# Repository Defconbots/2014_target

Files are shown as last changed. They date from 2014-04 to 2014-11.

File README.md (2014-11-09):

# Defconbots 2014 Target Hardware/Firmware

## Overview

This is the hardware and firmware design files for the defconbots 2014 laser target. It uses an [MSP430G2452](http://www.ti.com/product/msp430g2452) microcontroller and [TCS3414CS](http://www.ams.com/eng/Products/Light-Sensors/Color-Sensor/TCS3414) light detector to detect laser hits.

The board is designed in EagleCad 6.x. All part numbers are mouser numbers for easy BOM export.

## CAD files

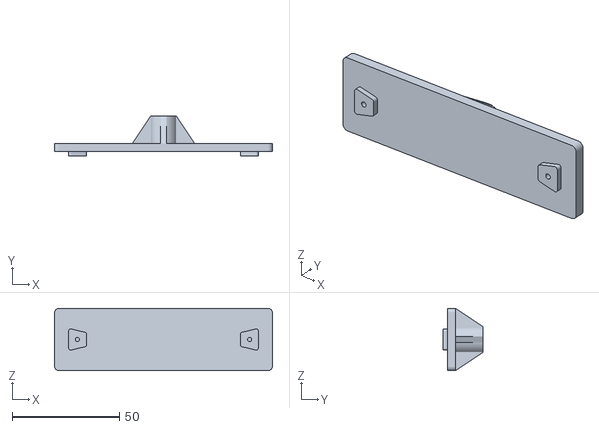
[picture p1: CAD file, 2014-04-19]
mech/train_mount.STL
101.6 x 18.5 x 29.0

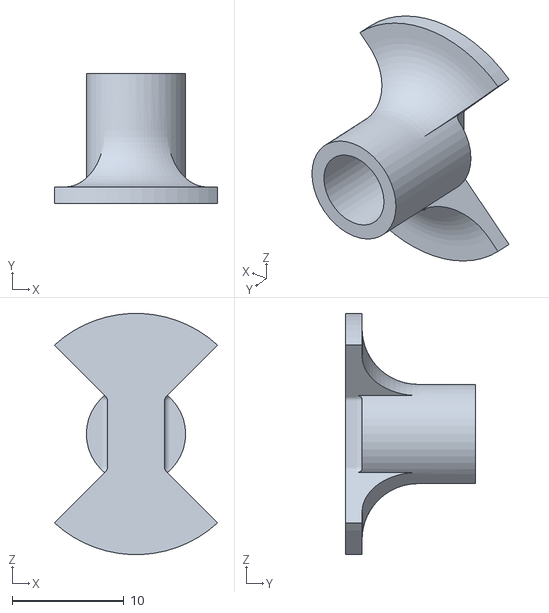
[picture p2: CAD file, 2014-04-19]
mech/pcb_mount.STL
14.6 x 11.7 x 21.6

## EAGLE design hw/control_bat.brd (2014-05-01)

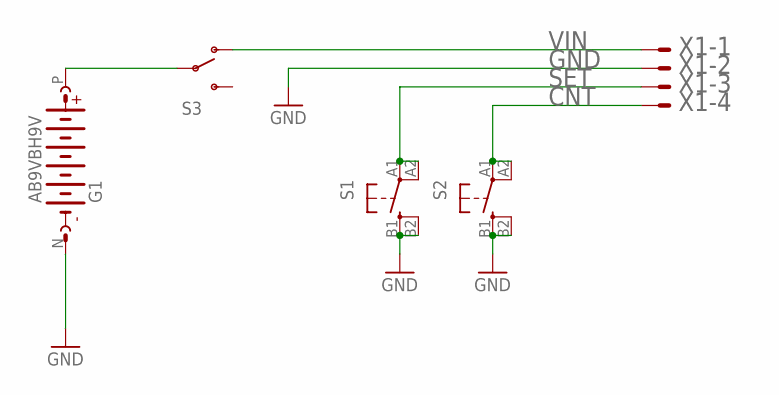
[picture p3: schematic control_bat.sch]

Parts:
G1: AB9VBH9V; BH9V-PC-ND
S1, S2: TAC_SWITCHD6F; D6F
S3: SWITCH-SPST; EG1270
X1: DF13-4P-1.25V(50); 53398-04

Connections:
CNT: S2.A1 (1), S2.A2 (2), X1.4
GND: G1.N (-), S1.B1 (3), S1.B2 (4), S2.B1 (3), S2.B2 (4), X1.2
unnamed: G1.P (+), S3.P$2
SET: S1.A1 (1), S1.A2 (2), X1.3
VIN: S3.P$1 (O), X1.1

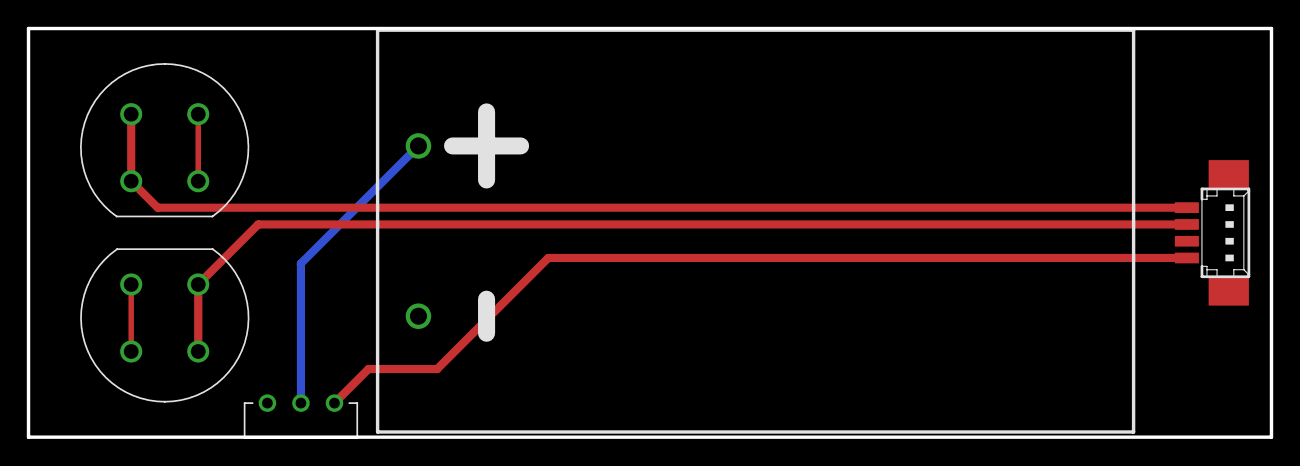
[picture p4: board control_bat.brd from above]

Board: 2 copper layers, 92.7 x 30.5 mm, 5 parts (0 on the bottom side), 5 nets.

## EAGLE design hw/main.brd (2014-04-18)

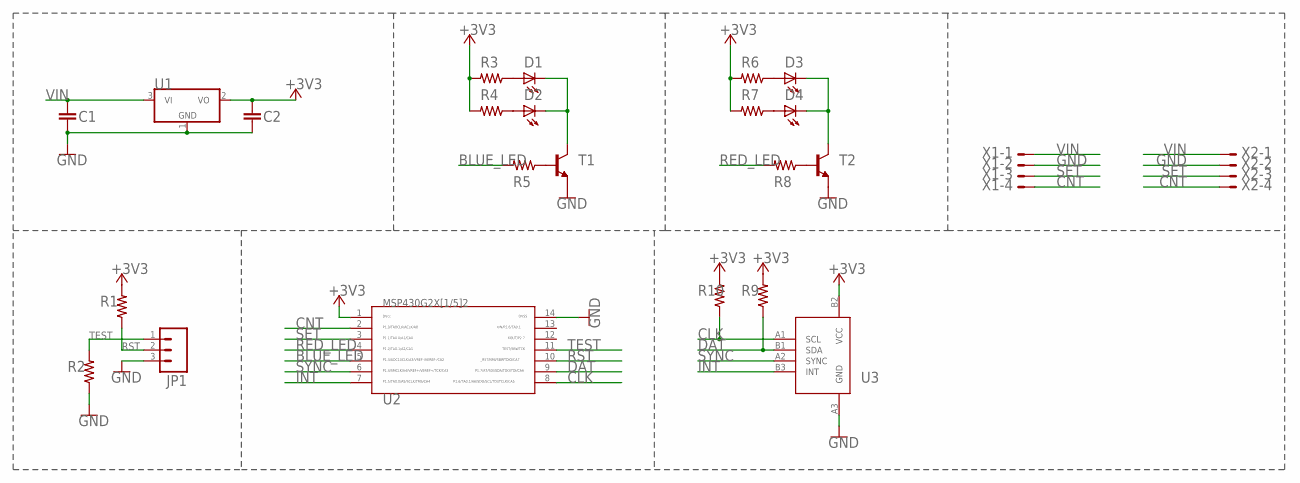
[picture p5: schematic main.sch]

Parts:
C1, C2: C1608X5R1C106M080AB; 0603-CAP
D1, D2: VLMB1300-GS08; LED-0603
D3, D4: VLMS1300-GS08; LED-0603
JP1: M03PTH; 1X03
R1, R2: RK73H1JTTD4702F; R0603
R3, R4, R5, R6, R7, R8: CRCW0603200RFKEA; R0603
R9, R10: RK73H1JTTD4701F; R0603
T1, T2: PMBT4401,215; SOT23-BEC
U1: MCP1703T-3002E/CB; SOT23
U2: MSP430G2452IPW14R; PW14
U3: TCS3414CS; CS-6
X1, X2: DF13-4P-1.25V(50); 53398-04

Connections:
+3V3: C2.1, R1.2, R3.2, R4.2, R6.2, R7.2, R9.2, R10.2, U1.2 (VO), U2.1, U3.B2 (VCC)
BLUE_LED: R5.2, U2.5
CLK: R10.1, U2.8, U3.A1 (SCL)
CNT: U2.2, X1.4, X2.4
DAT: R9.1, U2.9, U3.B1 (SDA)
GND: C1.2, C2.2, JP1.3, R2.1, T1.E, T2.E, U1.1 (GND), U2.14, U3.A3 (GND), X1.2, X2.2
INT: U2.7, U3.B3 (INT)
LED: D1.C, D2.C, T1.C
unnamed: D4.A, R7.1
unnamed: D3.C, D4.C, T2.C
unnamed: R8.1, T2.B
unnamed: D2.A, R4.1
unnamed: D1.A, R3.1
unnamed: D3.A, R6.1
unnamed: R5.1, T1.B
RED_LED: R8.2, U2.4
RST: JP1.2, R1.1, U2.10
SET: U2.3, X1.3, X2.3
SYNC: U2.6, U3.A2 (SYNC)
TEST: JP1.1, R2.2, U2.11
VIN: C1.1, U1.3 (VI), X1.1, X2.1

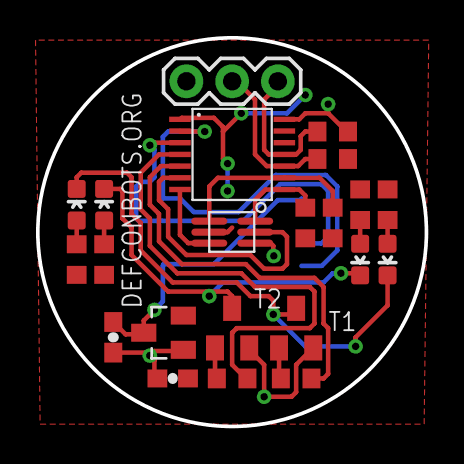
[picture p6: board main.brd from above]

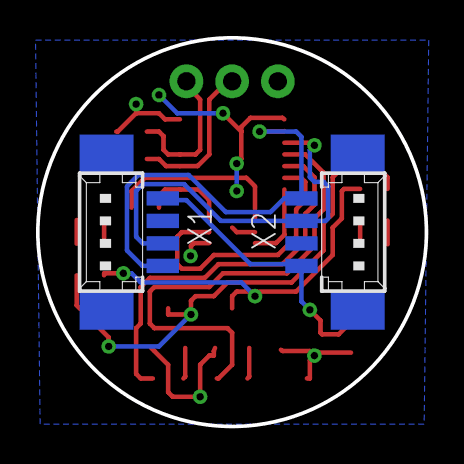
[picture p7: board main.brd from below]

Board: 2 copper layers, 21.6 x 21.6 mm, 24 parts (2 on the bottom side), 21 nets.

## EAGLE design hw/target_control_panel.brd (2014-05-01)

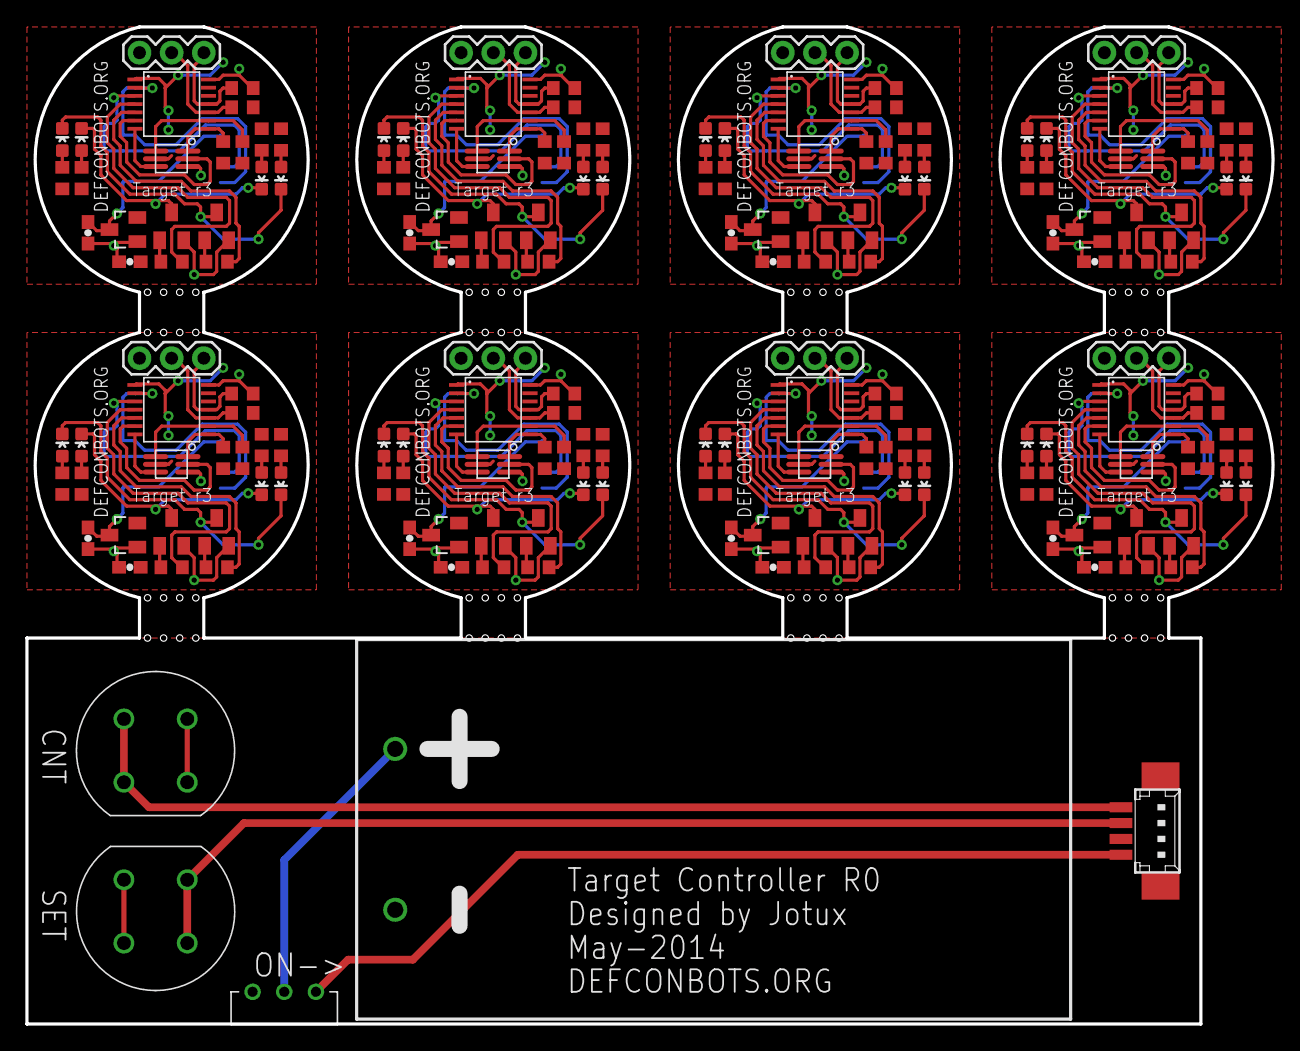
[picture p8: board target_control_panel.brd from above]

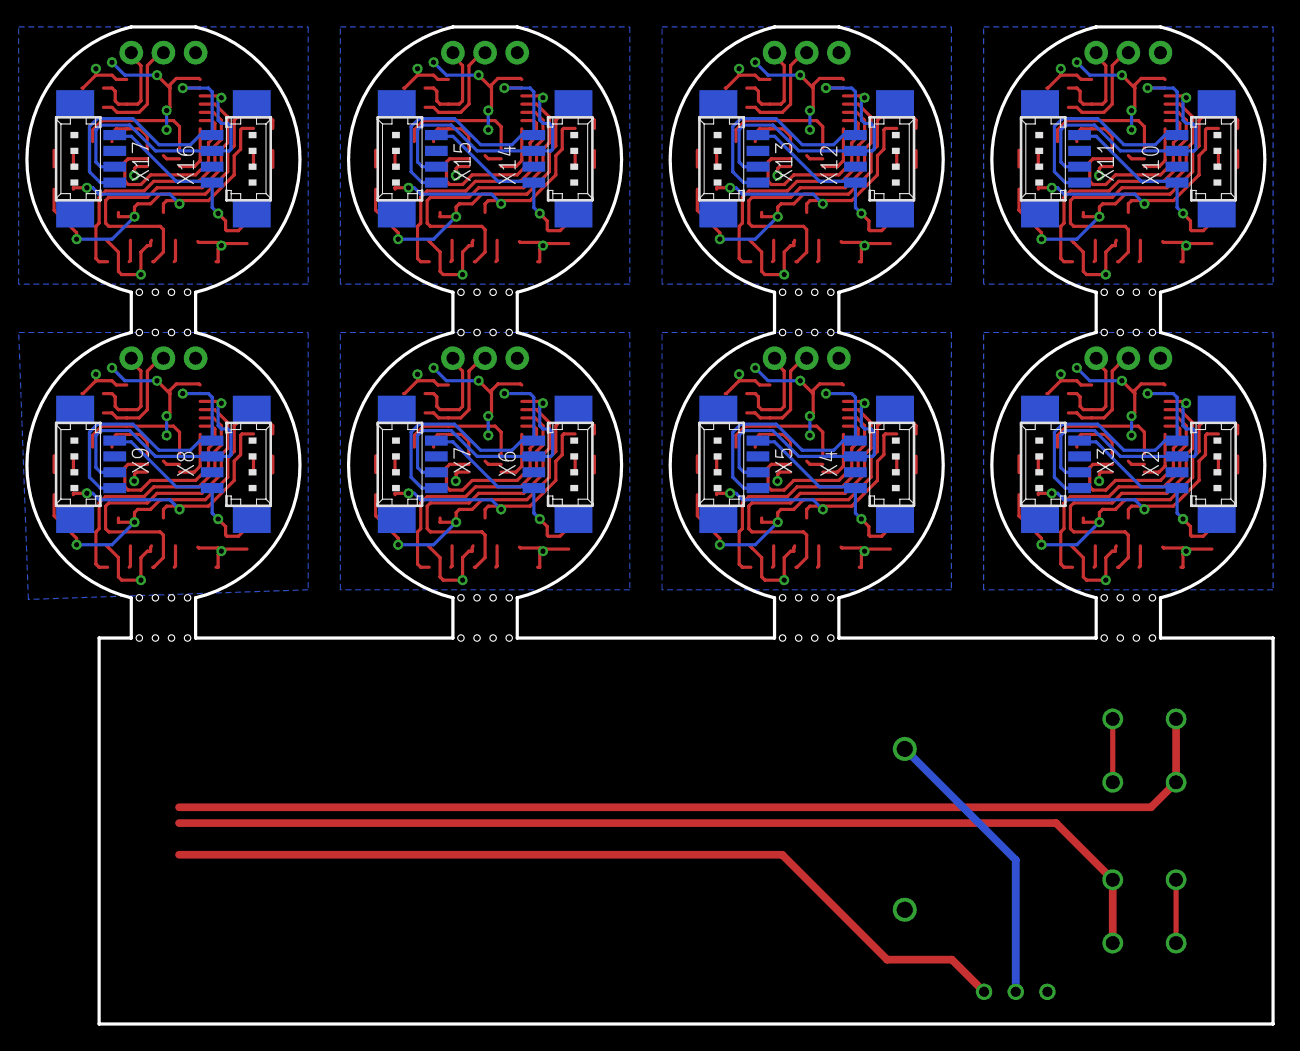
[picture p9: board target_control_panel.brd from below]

Board: 2 copper layers, 98.4 x 78.7 mm, 197 parts (16 on the bottom side), 173 nets.

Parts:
C1, C2, C3, C4, C5, C6, C7, C8, C9, C10, C11, C12, C13, C14, C15, C16: C1608X5R1C106M080AB; 0603-CAP
D1, D2, D5, D6, D9, D10, D13, D14, D17, D18, D21, D22, D25, D26, D29, D30: VLMB1300-GS08; LED-0603
D3, D4, D7, D8, D11, D12, D15, D16, D19, D20, D23, D24, D27, D28, D31, D32: VLMS1300-GS08; LED-0603
G1: AB9VBH9V; BH9V-PC-ND
JP1, JP2, JP3, JP4, JP5, JP6, JP7, JP8: 1X03
R1, R2, R15, R16, R25, R26, R35, R36, R45, R46, R55, R56, R65, R66, R75, R76: RK73H1JTTD4702F; R0603
R3, R4, R5, R6, R7, R8, R11, R12, R13, R14, R17, R18, R21, R22, R23, R24, R27, R28, R31, R32, R33, R34, R37, R38, R41, R42, R43, R44, R47, R48, R51, R52, R53, R54, R57, R58, R61, R62, R63, R64, R67, R68, R71, R72, R73, R74, R77, R78: CRCW0603200RFKEA; R0603
R9, R10, R19, R20, R29, R30, R39, R40, R49, R50, R59, R60, R69, R70, R79, R80: RK73H1JTTD4701F; R0603
S1, S2: D6F
S3: EG1270
T1, T2, T3, T4, T5, T6, T7, T8, T9, T10, T11, T12, T13, T14, T15, T16: PMBT4401,215; SOT23-BEC
U1, U4, U7, U10, U13, U16, U19, U22: MCP1703T-3002E/CB; SOT23
U2, U6, U9, U12, U15, U18, U21, U24: MSP430G2452IPW14R; PW14
U3, U5, U8, U11, U14, U17, U20, U23: TCS3414CS; CS-6
X1, X2, X3, X4, X5, X6, X7, X8, X9, X10, X11, X12, X13, X14, X15, X16, X17: DF13-4P-1.25V(50); 53398-04

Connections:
+3V1: C4.1, R11.2, R12.2, R14.2, R15.2, R17.2, R19.2, R20.2, U4.2, U5.B2, U6.1
+3V2: C6.1, R21.2, R22.2, R24.2, R25.2, R27.2, R29.2, R30.2, U7.2, U8.B2, U9.1
+3V3: C2.1, R1.2, R3.2, R4.2, R6.2, R7.2, R9.2, R10.2, U1.2, U2.1, U3.B2
+3V4: C8.1, R31.2, R32.2, R34.2, R35.2, R37.2, R39.2, R40.2, U10.2, U11.B2, U12.1
+3V5: C10.1, R41.2, R42.2, R44.2, R45.2, R47.2, R49.2, R50.2, U13.2, U14.B2, U15.1
+3V6: C12.1, R51.2, R52.2, R54.2, R55.2, R57.2, R59.2, R60.2, U16.2, U17.B2, U18.1
+3V7: C14.1, R61.2, R62.2, R64.2, R65.2, R67.2, R69.2, R70.2, U19.2, U20.B2, U21.1
+3V8: C16.1, R71.2, R72.2, R74.2, R75.2, R77.2, R79.2, R80.2, U22.2, U23.B2, U24.1
BLUE_LED: R5.2, U2.5
BLUE_LED1: R13.2, U6.5
BLUE_LED2: R23.2, U9.5
BLUE_LED3: R33.2, U12.5
BLUE_LED4: R43.2, U15.5
BLUE_LED5: R53.2, U18.5
BLUE_LED6: R63.2, U21.5
BLUE_LED7: R73.2, U24.5
CLK: R10.1, U2.8, U3.A1
CLK1: R20.1, U5.A1, U6.8
CLK2: R30.1, U8.A1, U9.8
CLK3: R40.1, U11.A1, U12.8
CLK4: R50.1, U14.A1, U15.8
CLK5: R60.1, U17.A1, U18.8
CLK6: R70.1, U20.A1, U21.8
CLK7: R80.1, U23.A1, U24.8
CNT: S2.A1, S2.A2, X1.4
CNT1: U2.2, X2.4, X3.4
CNT2: U6.2, X4.4, X5.4
CNT3: U9.2, X6.4, X7.4
CNT4: U12.2, X8.4, X9.4
CNT5: U15.2, X10.4, X11.4
CNT6: U18.2, X12.4, X13.4
CNT7: U21.2, X14.4, X15.4
CNT8: U24.2, X16.4, X17.4
DAT: R9.1, U2.9, U3.B1
DAT1: R19.1, U5.B1, U6.9
DAT2: R29.1, U8.B1, U9.9
DAT3: R39.1, U11.B1, U12.9
DAT4: R49.1, U14.B1, U15.9
DAT5: R59.1, U17.B1, U18.9
DAT6: R69.1, U20.B1, U21.9
DAT7: R79.1, U23.B1, U24.9
GND1: C1.2, C2.2, JP1.3, R2.1, T1.E, T2.E, U1.1, U2.14, U3.A3, X2.2, X3.2
GND2: C3.2, C4.2, JP2.3, R16.1, T3.E, T4.E, U4.1, U5.A3, U6.14, X4.2, X5.2
GND3: C5.2, C6.2, JP3.3, R26.1, T5.E, T6.E, U7.1, U8.A3, U9.14, X6.2, X7.2
GND4: C7.2, C8.2, JP4.3, R36.1, T7.E, T8.E, U10.1, U11.A3, U12.14, X8.2, X9.2
GND5: C9.2, C10.2, JP5.3, R46.1, T9.E, T10.E, U13.1, U14.A3, U15.14, X10.2, X11.2
GND6: C11.2, C12.2, JP6.3, R56.1, T11.E, T12.E, U16.1, U17.A3, U18.14, X12.2, X13.2
GND7: C13.2, C14.2, JP7.3, R66.1, T13.E, T14.E, U19.1, U20.A3, U21.14, X14.2, X15.2
GND8: C15.2, C16.2, JP8.3, R76.1, T15.E, T16.E, U22.1, U23.A3, U24.14, X16.2, X17.2
GND9: G1.N, S1.B1, S1.B2, S2.B1, S2.B2, X1.2
INT: U2.7, U3.B3
INT1: U5.B3, U6.7
INT2: U8.B3, U9.7
INT3: U11.B3, U12.7
INT4: U14.B3, U15.7
INT5: U17.B3, U18.7
INT6: U20.B3, U21.7
INT7: U23.B3, U24.7
LED: D1.C, D2.C, T1.C
LED1: D5.C, D6.C, T3.C
LED2: D9.C, D10.C, T5.C
LED3: D13.C, D14.C, T7.C
LED4: D17.C, D18.C, T9.C
LED5: D21.C, D22.C, T11.C
LED6: D25.C, D26.C, T13.C
LED7: D29.C, D30.C, T15.C
unnamed: D4.A, R7.1
unnamed: D3.C, D4.C, T2.C
unnamed: R8.1, T2.B
unnamed: G1.P, S3.P$2
unnamed: D5.A, R11.1
unnamed: D2.A, R4.1
unnamed: D1.A, R3.1
unnamed: D6.A, R12.1
unnamed: R13.1, T3.B
unnamed: D3.A, R6.1
unnamed: D7.A, R14.1
unnamed: D8.A, R17.1
unnamed: D7.C, D8.C, T4.C
unnamed: R18.1, T4.B
unnamed: D9.A, R21.1
unnamed: D10.A, R22.1
unnamed: R23.1, T5.B
unnamed: R5.1, T1.B
unnamed: D11.A, R24.1
unnamed: D12.A, R27.1
unnamed: D11.C, D12.C, T6.C
unnamed: R28.1, T6.B
unnamed: D13.A, R31.1
unnamed: D14.A, R32.1
unnamed: R33.1, T7.B
unnamed: D15.A, R34.1
unnamed: D16.A, R37.1
unnamed: D15.C, D16.C, T8.C
unnamed: R38.1, T8.B
unnamed: D17.A, R41.1
unnamed: D18.A, R42.1
unnamed: R43.1, T9.B
unnamed: D19.A, R44.1
unnamed: D20.A, R47.1
unnamed: D19.C, D20.C, T10.C
unnamed: R48.1, T10.B
unnamed: D21.A, R51.1
unnamed: D22.A, R52.1
unnamed: R53.1, T11.B
unnamed: D23.A, R54.1
unnamed: D24.A, R57.1
unnamed: D23.C, D24.C, T12.C
unnamed: R58.1, T12.B
unnamed: D25.A, R61.1
unnamed: D26.A, R62.1
unnamed: R63.1, T13.B
unnamed: D27.A, R64.1
unnamed: D28.A, R67.1
unnamed: D27.C, D28.C, T14.C
unnamed: R68.1, T14.B
unnamed: D29.A, R71.1
unnamed: D30.A, R72.1
unnamed: R73.1, T15.B
unnamed: D31.A, R74.1
unnamed: D32.A, R77.1
unnamed: D31.C, D32.C, T16.C
unnamed: R78.1, T16.B
RED_LED: R8.2, U2.4
RED_LED1: R18.2, U6.4
RED_LED2: R28.2, U9.4
RED_LED3: R38.2, U12.4
RED_LED4: R48.2, U15.4
RED_LED5: R58.2, U18.4
RED_LED6: R68.2, U21.4
RED_LED7: R78.2, U24.4
RST: JP1.2, R1.1, U2.10
RST1: JP2.2, R15.1, U6.10
RST2: JP3.2, R25.1, U9.10
RST3: JP4.2, R35.1, U12.10
RST4: JP5.2, R45.1, U15.10
RST5: JP6.2, R55.1, U18.10
RST6: JP7.2, R65.1, U21.10
RST7: JP8.2, R75.1, U24.10
SET: S1.A1, S1.A2, X1.3
SET1: U2.3, X2.3, X3.3
SET2: U6.3, X4.3, X5.3
SET3: U9.3, X6.3, X7.3
SET4: U12.3, X8.3, X9.3
SET5: U15.3, X10.3, X11.3
SET6: U18.3, X12.3, X13.3
SET7: U21.3, X14.3, X15.3
SET8: U24.3, X16.3, X17.3
SYNC: U2.6, U3.A2
SYNC1: U5.A2, U6.6
SYNC2: U8.A2, U9.6
SYNC3: U11.A2, U12.6
SYNC4: U14.A2, U15.6
SYNC5: U17.A2, U18.6
SYNC6: U20.A2, U21.6
SYNC7: U23.A2, U24.6
TEST: JP1.1, R2.2, U2.11
TEST1: JP2.1, R16.2, U6.11
TEST2: JP3.1, R26.2, U9.11
TEST3: JP4.1, R36.2, U12.11
TEST4: JP5.1, R46.2, U15.11
TEST5: JP6.1, R56.2, U18.11
TEST6: JP7.1, R66.2, U21.11
TEST7: JP8.1, R76.2, U24.11
VIN: S3.P$1, X1.1
VIN1: C1.1, U1.3, X2.1, X3.1
VIN2: C3.1, U4.3, X4.1, X5.1
VIN3: C5.1, U7.3, X6.1, X7.1
VIN4: C7.1, U10.3, X8.1, X9.1
VIN5: C9.1, U13.3, X10.1, X11.1
VIN6: C11.1, U16.3, X12.1, X13.1
VIN7: C13.1, U19.3, X14.1, X15.1
VIN8: C15.1, U22.3, X16.1, X17.1

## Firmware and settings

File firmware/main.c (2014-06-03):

#include "global.h"
#include "hw.h"
#include "schedule.h"
#include "clock.h"
#include "delay.h"
#include "hardware_init.h"
#include "interrupt.h"
#include "state.h"
#include "tcs3414_color_sensor.h"
#include "juicy.h"

// One target needs pullups enabled for the set/cnt lines
//#define ENABLE_PULLUPS

//::::::::::::::::::::::::::::::::::::::::::::::::::::::::::::::::::::::::::::::
//                        Locals and State Machine config
//::::::::::::::::::::::::::::::::::::::::::::::::::::::::::::::::::::::::::::::
StateMachine s;

enum Event
{
    DEFAULT_EVENTS, // Enter, idle, exit
    STUN,           // Verified laser hit
    STUN_TIMEOUT,   // Timeout from hit delay
    CONFIG,         // Hit detected by another target or target reset
    CNT_TICK,       // CNT tick to tell us how many hits to use
    KILL            // When stuns >= kill count
};

void Detecting(uint8_t ev);
void Config(uint8_t ev);
void Stunned(uint8_t ev);
void Dead(uint8_t ev);


const Transition rules[] =
{
//  Current State + Event         = New State
    {Detecting,     STUN,           Stunned},
    {Detecting,     CONFIG,         Config},
    {Config,        CONFIG,         Detecting},
    {Config,        KILL,           Dead},
    {Stunned,       STUN_TIMEOUT,   Detecting},
    {Stunned,       KILL,           Dead},
    {Dead,          CONFIG,         Config}
};

static uint8_t kill_count = 0xFF;

static uint16_t red_thresh = 0;
static uint16_t green_thresh = 0;

//::::::::::::::::::::::::::::::::::::::::::::::::::::::::::::::::::::::::::::::
//                              Utilities
//::::::::::::::::::::::::::::::::::::::::::::::::::::::::::::::::::::::::::::::
void HwInit(void)
{
    // LEDs
    HW_OUTPUT(RED);
    RED_OFF();
    HW_OUTPUT(BLUE);
    BLUE_OFF();

    // TCS3414
    HW_OUTPUT(SYNC);
    SYNC_LOW();

    // Intermodule Communication
    HW_INPUT(SET);
    HW_INPUT(CNT);
#ifdef ENABLE_PULLUPS
    HW_PULL_UP(SET);
    HW_PULL_UP(CNT);
#endif
}

void RecordAmbientLight(uint8_t num_samples)
{
    uint8_t i = 0;
    uint16_t red_sum = 0;
    uint16_t green_sum = 0;
    Delay(500); // wait for it to settle after init
    for (i = 0;i < num_samples;i++)
    {
        red_sum += Tcs3414ReadColor(COLOR_RED);
        green_sum += Tcs3414ReadColor(COLOR_GREEN);
        Delay(100);
    }
    red_thresh = ((red_sum / num_samples) * 15) / 10;
    green_thresh = ((green_sum / num_samples) * 12) / 10;
}

void BroadcastHit(void)
{
    // Pull the set line low
    HW_OUTPUT(SET);
    HW_SET_LOW(SET);
}

void BroadcastReset(void)
{
    // Toggle high->low->high to force a CONFIG event on other targets
    HW_SET_HIGH(SET);
    Delay(150);
    HW_SET_LOW(SET);
    Delay(150);
    // Return to input/pullup state
    HW_SET_HIGH(SET);
    HW_INPUT(SET);
}

//::::::::::::::::::::::::::::::::::::::::::::::::::::::::::::::::::::::::::::::
//                              Signal generators
//::::::::::::::::::::::::::::::::::::::::::::::::::::::::::::::::::::::::::::::
void CheckForHit(void)
{
    static uint32_t laser_hit_count = 0;
    uint16_t red   = Tcs3414ReadColor(COLOR_RED);
    uint16_t green = Tcs3414ReadColor(COLOR_GREEN);
    uint8_t hit = (red > red_thresh) && (green < green_thresh);
    if (hit)
    {
        laser_hit_count++;
    }
    else
    {
        if (laser_hit_count >= 9 && laser_hit_count < 22) //450-1100ms
        {
            StateMachinePublishEvent(&s,STUN);
        }
        laser_hit_count = 0;
    }
}

void SetPoll(void)
{
    static uint8_t toggle = 0;
    uint8_t down = !SET_READ();
    if (down && !toggle)
    {
        if (s.state == Config && kill_count == 0)
        {
            StateMachinePublishEvent(&s, KILL);
        }
        else
        {
            StateMachinePublishEvent(&s, CONFIG);
        }
        toggle = 1;
    }
    else if (!down && toggle)
    {
        toggle = 0;
    }
}

void CntPoll(void)
{
    static uint8_t toggle = 0;
    uint8_t down = !CNT_READ();
    if (down && !toggle)
    {
        StateMachinePublishEvent(&s,CNT_TICK);
        toggle = 1;
    }
    else if (!down && toggle)
    {
        toggle = 0;
    }
}


//::::::::::::::::::::::::::::::::::::::::::::::::::::::::::::::::::::::::::::::
//                             State functions
//::::::::::::::::::::::::::::::::::::::::::::::::::::::::::::::::::::::::::::::
void Detecting(uint8_t ev)
{
    switch (ev)
    {
        case ENTER:
        {
            CallbackMode(CheckForHit,ENABLED);
            CallbackMode(SetPoll,ENABLED);
            JuicyBlueOn();
            break;
        }
        case EXIT:
        {
            CallbackMode(CheckForHit,DISABLED);
            CallbackMode(SetPoll,DISABLED);
            break;
        }
    }
}

void Config(uint8_t ev)
{
    static uint8_t cnt_state = 0;
    switch (ev)
    {
        case ENTER:
        {
            if (kill_count)
            {
                JuicyBlueOff();
            }
            CallbackMode(CntPoll,ENABLED);
            CallbackMode(SetPoll,ENABLED);
            break;
        }
        case CNT_TICK:
        {
            if (cnt_state == 0)
            {
                cnt_state = 1;
                kill_count = 1;
            }
            else
            {
                kill_count++;
            }
            uint8_t i = kill_count;
            while (i--)
            {
                JuicyBothOn();
                JuicyBothOff();
            }
            break;
        }
        case EXIT:
        {
            CallbackMode(CntPoll,DISABLED);
            CallbackMode(SetPoll,DISABLED);
            cnt_state = 0;
            break;
        }
    }
}

void Stunned(uint8_t ev)
{
    switch (ev)
    {
        case ENTER:
        {
            BroadcastHit();
            JuicyBlueOff();
            JuicyRedOn();
            Tcs3414Shutdown();
            kill_count--;
            break;
        }
        case IDLE:
        {
            Delay(1000);
            StateMachinePublishEvent(&s, kill_count ? STUN_TIMEOUT : KILL);
            break;
        }
        case EXIT:
        {
            BroadcastReset();
            Tcs3414Init();
            JuicyRedOff();
            break;
        }
    }
}

void Dead(uint8_t ev)
{
    switch (ev)
    {
        case ENTER:
        {
            CallbackMode(SetPoll,ENABLED);
            Tcs3414Shutdown();
            break;
        }
        case EXIT:
        {
            CallbackMode(SetPoll,DISABLED);
            Tcs3414Init();
            break;
        }
    }
}

//::::::::::::::::::::::::::::::::::::::::::::::::::::::::::::::::::::::::::::::
//                                  Entry
//::::::::::::::::::::::::::::::::::::::::::::::::::::::::::::::::::::::::::::::
void main(void)
{

    WD_STOP();
    ClockConfig(8);
    ScheduleTimerInit();
    HwInit();
    Tcs3414Init();
    s = StateMachineCreate(rules,sizeof(rules), Detecting);
    _EINT();
    JuicyBlueOn();
    RecordAmbientLight(25);
    JuicyBlueOff();
    Delay(1000);
    CallbackRegister(CheckForHit,50);
    CallbackRegister(CntPoll,100);
    CallbackRegister(SetPoll,100);
    while (1)
    {
        StateMachineRun(&s);
    }
}

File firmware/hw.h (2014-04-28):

/**
@file hw.h
@brief Definitions hardware config
@author Joe Brown
*/
#ifndef HW_H
#define HW_H
//::::::::::::::::::::::::::::::::::::::::::::::::::::::::::::::::::::::::::::::
//            __  __                  __
//           / / / /____ _ _____ ____/ /_      __ ____ _ _____ ___
//          / /_/ // __ `// ___// __  /| | /| / // __ `// ___// _ \
//         / __  // /_/ // /   / /_/ / | |/ |/ // /_/ // /   /  __/
//        /_/ /_/ \__,_//_/    \__,_/  |__/|__/ \__,_//_/    \___/
//
//::::::::::::::::::::::::::::::::::::::::::::::::::::::::::::::::::::::::::::::
// LEDs
#define RED             1,2
#define RED_ON()        HW_SET_HIGH(RED)
#define RED_OFF()       HW_SET_LOW(RED)
#define RED_TOGGLE()    HW_SET_TOGGLE(RED)

#define BLUE            1,3
#define BLUE_ON()       HW_SET_HIGH(BLUE)
#define BLUE_OFF()      HW_SET_LOW(BLUE)
#define BLUE_TOGGLE()   HW_SET_TOGGLE(BLUE)

// Inter-module comm.
#define CNT             1,0
#define CNT_READ()      HW_READ(CNT)
#define SET             1,1
#define SET_READ()      HW_READ(SET)

// Interrupt config
#define NUM_P1_INTS     4

// Light sensor
#define SYNC            1,4
#define SYNC_LOW()      HW_SET_LOW(SYNC)
#define INT             1,5

#define DAT             1,7
#define DAT_LOW()       HW_SET_LOW(DAT)
#define DAT_HIGH()      HW_SET_HIGH(DAT)
#define DAT_INPUT()     HW_INPUT(DAT)
#define DAT_OUTPUT()    HW_OUTPUT(DAT)
#define DAT_READ()      HW_READ(DAT)
#define CLK             1,6
#define CLK_LOW()       HW_SET_LOW(CLK)
#define CLK_HIGH()      HW_SET_HIGH(CLK)
#define CLK_INPUT()     HW_INPUT(CLK)
#define CLK_OUTPUT()    HW_OUTPUT(CLK)

#endif

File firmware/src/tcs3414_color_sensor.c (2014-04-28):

#include "global.h"
#include "tcs3414_color_sensor.h"
#include "i2c.h"
#include "delay.h"
#include "schedule.h"

#define TCS3414_ADDRESS                           0x39
#define TCS3414_WRITE_ADDRESS                     (TCS3414_ADDRESS << 1)
#define TCS3414_READ_ADDRESS                      (TCS3414_ADDRESS << 1 | 1)

#define TCS3414_COMMAND_BIT                       0x80
#define TCS3414_WORD_BIT                          0x20

#define TCS3414_REGISTER_CONTROL                  0x00
#define TCS3414_REGISTER_TIMING                   0x01
#define TCS3414_REGISTER_INTERRUPT                0x02
#define TCS3414_REGISTER_INTSOURCE                0x03
#define TCS3414_REGISTER_PARTNO_REVID             0x04
#define TCS3414_REGISTER_GAIN                     0x07
#define TCS3414_REGISTER_LOWTHRESHOLD_LOWBYTE     0x08
#define TCS3414_REGISTER_LOWTHRESHOLD_HIGHBYTE    0x09
#define TCS3414_REGISTER_HIGHTHRESHOLD_LOWBYTE    0x0A
#define TCS3414_REGISTER_HIGHTHRESHOLD_HIGHBYTE   0x0B
#define TCS3414_REGISTER_GREENLOW                 0x10
#define TCS3414_REGISTER_GREENHIGH                0x11
#define TCS3414_REGISTER_REDLOW                   0x12
#define TCS3414_REGISTER_REDHIGH                  0x13
#define TCS3414_REGISTER_BLUELOW                  0x14
#define TCS3414_REGISTER_BLUEHIGH                 0x15
#define TCS3414_REGISTER_CLEARLOW                 0x16
#define TCS3414_REGISTER_CLEARHIGH                0x17

//Control Register
#define TCS3414_CONTROL_POWERON                   0x01
#define TCS3414_CONTROL_POWEROFF                  0x00
#define TCS3414_CONTROL_ADC_EN                    0x02
#define TCS3414_CONTROL_ADC_VALID                 0x10

//Gain Register
#define TCS3414_GAIN_GAINMASK                     0x30
#define TCS3414_GAIN_PRESCALARMASK                0x07
#define TCS3414_GAIN_1X                           0x00
#define TCS3414_GAIN_4X                           0x10
#define TCS3414_GAIN_16X                          0x20
#define TCS3414_GAIN_64X                          0x30

//Timing Register
#define TCS3414_INTEGRATION_TIME_MASK             0x03
#define TCS3414_INTEGRATION_TIME_12MS             0x00
#define TCS3414_INTEGRATION_TIME_100MS            0x01
#define TCS3414_INTEGRATION_TIME_400MS            0x02

uint8_t ReadByte(uint8_t command)
{
    I2cStart();
    I2cWrite(TCS3414_WRITE_ADDRESS);
    I2cWrite(command);
    I2cStop();
    I2cStart();
    I2cWrite(TCS3414_READ_ADDRESS);
    uint16_t ret = I2cRead();
    I2cStop();
    return ret;
}
void WriteByte(uint8_t command, uint8_t value)
{
    I2cStart();
    I2cWrite(TCS3414_WRITE_ADDRESS);
    I2cWrite(command);
    I2cWrite(value);
    I2cStop();
}

void Tcs3414Init(void)
{
    // Turn off
    //WriteByte(TCS3414_REGISTER_CONTROL | TCS3414_COMMAND_BIT, TCS3414_CONTROL_POWEROFF);
    //Delay(10);
    // Turn on
    WriteByte(TCS3414_REGISTER_CONTROL | TCS3414_COMMAND_BIT, TCS3414_CONTROL_POWERON);
    // Integration time to 100ms
    WriteByte(TCS3414_REGISTER_TIMING | TCS3414_COMMAND_BIT, TCS3414_INTEGRATION_TIME_100MS);
    // ADC gain to 4X
    WriteByte(TCS3414_REGISTER_GAIN | TCS3414_COMMAND_BIT, TCS3414_GAIN_4X);
    // Turn on the ADC.
    WriteByte(TCS3414_REGISTER_CONTROL | TCS3414_COMMAND_BIT, (TCS3414_CONTROL_POWERON | TCS3414_CONTROL_ADC_EN));
}

void Tcs3414Shutdown(void)
{
    WriteByte(TCS3414_REGISTER_CONTROL | TCS3414_COMMAND_BIT, TCS3414_CONTROL_POWEROFF);
}

ColorReading Tcs3414ReadAllColors(void)
{
    ColorReading color;
    color.red   = Tcs3414ReadColor(COLOR_RED);
    color.green = Tcs3414ReadColor(COLOR_GREEN);
    color.blue  = Tcs3414ReadColor(COLOR_BLUE);
    color.clear = Tcs3414ReadColor(COLOR_CLEAR);
    return color;
}

uint16_t Tcs3414ReadColor(enum Color c)
{
    uint8_t low = 0;
    uint8_t high = 0;
    switch (c)
    {
        case COLOR_RED:
        {
            low  = ReadByte(TCS3414_REGISTER_REDLOW  | TCS3414_COMMAND_BIT);
            high = ReadByte(TCS3414_REGISTER_REDHIGH | TCS3414_COMMAND_BIT);
            break;
        }
        case COLOR_GREEN:
        {
            low  = ReadByte(TCS3414_REGISTER_GREENLOW  | TCS3414_COMMAND_BIT);
            high = ReadByte(TCS3414_REGISTER_GREENHIGH | TCS3414_COMMAND_BIT);
            break;
        }
        case COLOR_BLUE:
        {
            low  = ReadByte(TCS3414_REGISTER_BLUELOW  | TCS3414_COMMAND_BIT);
            high = ReadByte(TCS3414_REGISTER_BLUEHIGH | TCS3414_COMMAND_BIT);
            break;
        }
        case COLOR_CLEAR:
        {
            low  = ReadByte(TCS3414_REGISTER_CLEARLOW  | TCS3414_COMMAND_BIT);
            high = ReadByte(TCS3414_REGISTER_CLEARHIGH | TCS3414_COMMAND_BIT);
            break;
        }
    }
    return ((high << 8) | low);
}

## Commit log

2013-10-27 Rename repo to generic target and add firmware. Firmware is notional right now and is unlikely to even compile.
    [main.brd, main.sch]
2013-10-27 Fix pin on laser input
    [hw.h]
2013-10-29 Hw up and running with dasblinkenlights sample
2013-11-02 Detects laster hits and blinks the green LED for each hit detected.
2013-11-13 Remove transistor and switch laser input to ADC polling.
    [main.brd, main.sch]
2013-11-14 Fix resistor value for light detector.
    [main.brd, main.sch]
2014-04-03 Updated target to simplify circuit and make immune to spurious light sources.
    The design has been reduced in size from ~40mm diameter to ~21mm diameter. The sensor was changed from a single-color (red) detector to a full-spectrum + white sensor since the old version would get 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
    [main.brd, main.sch]
2014-04-18 Fix errors in PCB found after initial testing.
    - Swapped pullup/down on RST/TEST lines (they were backward).
    - Added 4.7k pullups to i2c lines (maybe don't need but the signal is a little ugly without them)
    - Removed silkscreen of part numbers since they're not very readable anyway
    [main.brd, main.sch]
2014-04-18 Preliminary firmware for rev2 hardware.
    - Updated hw defs for new board
    - Added bitbanged i2c driver (USI on the g2452 was cumbersome)
    - Added tcs3414 light sensor driver
    - Initial code just reads clear channel for demo
    - Other minor tweaks
2014-04-19 Add 3d models for train and PCB mount hardware
    [pcb_mount.STL, train_mount.STL]
2014-04-25 First pass implementing logic for target with new sensor. Also implemented intermodule config/halt.
2014-04-28 Refine target implementation.
    -Add ambient-light detection on powerup
    -Clean up delay functions (pass number of milliseconds instead of num * millisecond)
    -Tune color sensor
    -Add blink to show kill count setting
2014-04-28 Clean up red LED behavior.
2014-04-30 Add battery/control board.
    [control_bat.brd, control_bat.sch]
2014-05-01 Fix battery orientation in control board. Panelize for manufacturing.
    [control_bat.brd, control_bat.sch, target_control_panel.brd]
2014-05-03 Remove adc, since we don't need it.
2014-05-03 Add some juiciness to the LEDs. Tweak detection settings. Add hit and reset broadcasting.
    [interrupt.c, main.c]
2014-05-15 Extend BroadcastReset Delays to ensure they are detected on the other targets and add ifdef to disable pullups.
    If pullups are enabled on all the targets then when a target detects a hit it will not be able to pull the line low. We could add pullups on the control board but since there is no regulation there i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
2014-05-28 Switch cnt/set to polling. Minor tweaks for usability.
2014-06-03 Fix bug where blue LED would turn off, beautifully, when a hit was broadcast to a dead unit
    [main.c]

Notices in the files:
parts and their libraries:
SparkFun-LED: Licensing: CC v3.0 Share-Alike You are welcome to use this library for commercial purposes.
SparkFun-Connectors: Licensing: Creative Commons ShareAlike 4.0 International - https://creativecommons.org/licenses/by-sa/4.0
